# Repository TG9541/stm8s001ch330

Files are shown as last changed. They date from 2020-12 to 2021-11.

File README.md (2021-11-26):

# STM8S001J3M3 with CH330N USB Serial Dongle 



This is a design for an easy to use and easy to make key-chain sized STM8S001J3M3 dongle with CH330N USB-UART, e.g. for [STM8 eForth](https://github.com/TG9541/stm8ef) (which turns it into an interactive development environment). It can also be for interfacing, e.g., 1Wire or I2C sensors, as an IR-code transmitter, or prototyping software for "Low density" STM8S µCs (which all have 8K Flash, 1K RAM and 128-640 bytes EEPROM). If you're an 8bit computing and retro-computing affectionado: the typical performance is like a "6502 @ >20MHz" and it's about as easy to program.



The STM8S001J3M3 UART works in "half-duplex" mode (`PD5/UART_TX`) with the CH330N USB-UART in wired-or configuration (D1). The internal pull-up of `PD5` should be active (the STM8 eForth [STM8S001J3](https://github.com/TG9541/stm8ef/tree/master/STM8S001J3) base image takes care of that). This configuration allows IAP (in application programming) in Forth and ICP (in circuit programming) through `PD1/SWIM` through pin8 of the µC.

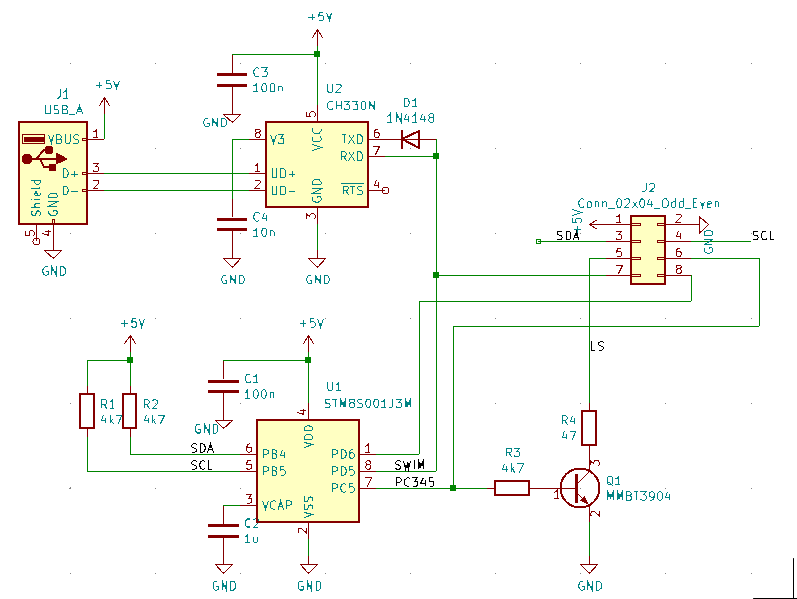
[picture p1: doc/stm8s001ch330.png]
schematics


All components, including the PCB and the SMD USB-A connector are easy to obtain (e.g. [here](https://www.aliexpress.com/item/32900067411.html) for the USB connector - refer to the BOM is in the docs folder).



### Signals on Header J2

J2 provides the following signals:

Pin|Label|Pin STM8S001|GPIO|Features
-|-|-|-|-
1|5V|4|VDD|5V from USB or external supply
2|GND|2|VSS|GND
3|SDA|5|PB5 | I2C_SDA w/ 4k7 pull-up
-||5|PA3 | TIM2_CH3, [SPI_NSS], [UART1_TX]
4|SCL|6|PB4 | I2C_SCL w/ 4k7 pull-up, [ADC_ETR]
5|LSS| |PC3| NPN "Low Side" switch w/ 47R, e.g. IR LED @ 100mA
6|PC3|7|PC3 | TIM1_CH3, [TLI], [TIM1_CH1N] same as LS NPN base
-||7|PC4 | TIM1_CH4, CLK_CCO, AIN2, [TIM1_CH3]
-||7|PC5 | SPI_SCK, [TIM2_CH1]
7|SWIM|8|PD1 | SWIM
-||8|PC6 | SPI_MOSI, [TIM1_CH1]
-||8|PD3 | TIM2_CH2, TIM2_CH2, ADC_ETR
-||8|PD5 | UART1_TX, AIN5
8|PD6|1|PD6| UART1_RX, AIN6
-||1|PA1|[OSC_IN]
 
Note: the circuit relies on the USB port short-circuit protection!

### Example use-cases

* Pins 1, 2, 3 and 4 can be used for testing I2C modules w/ 5V supply (e.g. [STM8 eForth I2C Master](https://gist.github.com/TG9541/5c3405320794d91ef8129734a4bfc880#gistcomment-3565181))
* Pins 1 and 5 can be used for a 100mA IR LED (e.g. [IR Remote Control](https://gist.github.com/TG9541/40b811c3a611eb02ba9e3693f99222ac))
* Pins 1, 2 and 8 can be used for connecting an IR receiver
* Pins 1, 2 and 3 can control a [WS2812 LED strip](https://gist.github.com/TG9541/1761fa86b425a0c909b7bd1cc8017c2b)
* Pin 3 and can be used for RS485 after remapping the UART to PA3 (e.g. using the Forth SWIMCOM binary)
* [Learn programming Forth ...](https://github.com/TG9541/stm8ef/wiki/STM8-eForth-Programming)

### Populating the PCB

Populating the PCB by hand is easy. I recommend starting with D1, then U1, U2, C1 and C2. On the front side populate Q1 and the passive components first, then J1 and finally J2. 

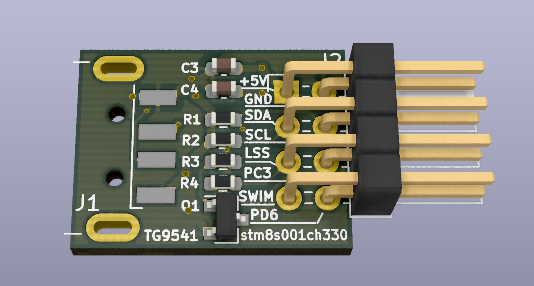
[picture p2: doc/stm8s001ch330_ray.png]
dongle


The following components are optional (e.g. if J2 isn't needed): R1, R2, R3, R4, Q1 and J2.

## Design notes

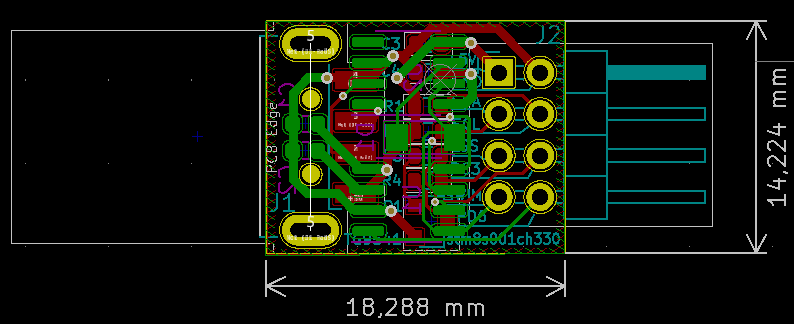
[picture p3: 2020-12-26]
doc/stm8s001ch330_copper.png

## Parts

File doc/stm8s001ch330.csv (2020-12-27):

Reference | Value | Footprint | Datasheet
C2 | 1u | Capacitor_SMD:C_0603_1608Metric | ~
J1 | USB_A | Connector_USB:USB_A_CNCTech_1001-011-01101_Horizontal | ~
C4 | 10n | Capacitor_SMD:C_0603_1608Metric | ~
C3 | 100n | Capacitor_SMD:C_0603_1608Metric | ~
C1 | 100n | Capacitor_SMD:C_0603_1608Metric | ~
R1 | 4k7 | Resistor_SMD:R_0603_1608Metric | ~
R2 | 4k7 | Resistor_SMD:R_0603_1608Metric | ~
D1 | 1N4148 | Diode_SMD:D_MiniMELF | ~
R3 | 4k7 | Resistor_SMD:R_0603_1608Metric | ~
R4 | 47 | Resistor_SMD:R_0603_1608Metric | ~
J2 | Conn_02x04_Odd_Even | Connector_PinHeader_2.54mm:PinHeader_2x04_P2.54mm_Horizontal | ~
Q1 | MMBT3904 | Package_TO_SOT_SMD:SOT-23 | https://www.onsemi.com/pub/Collateral/2N3903-D.PDF
U2 | CH330N | Package_SO:SOIC-8_3.9x4.9mm_P1.27mm | http://www.wch.cn/downloads/file/240.html
U1 | STM8S001J3M | Package_SO:SOIC-8_3.9x4.9mm_P1.27mm | https://www.st.com/resource/en/datasheet/stm8s001j3.pdf

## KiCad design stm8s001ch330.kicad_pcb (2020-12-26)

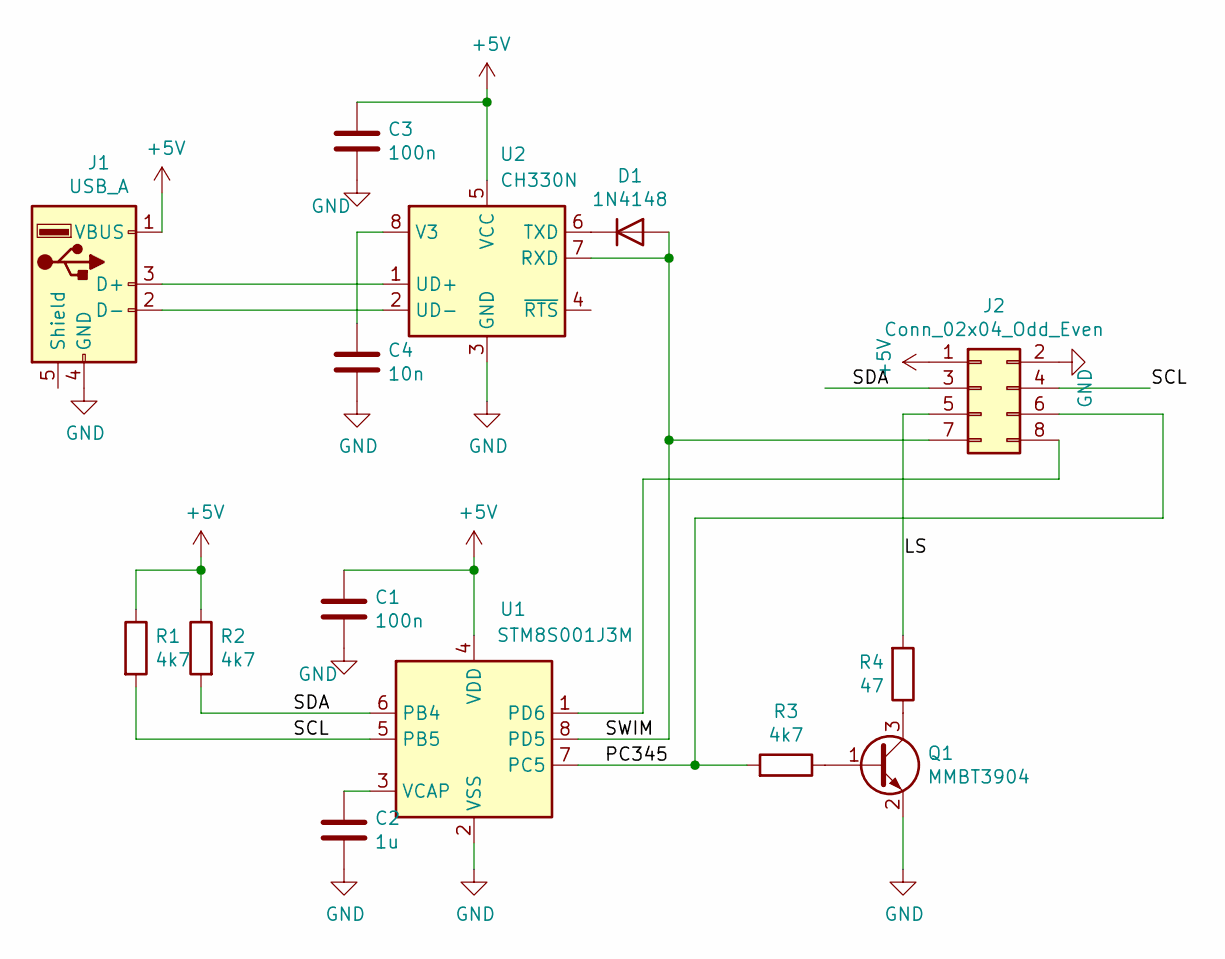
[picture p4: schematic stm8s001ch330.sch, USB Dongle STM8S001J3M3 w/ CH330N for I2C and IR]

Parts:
C1, C3: 100n; C_0603_1608Metric
C2: 1u; C_0603_1608Metric
C4: 10n; C_0603_1608Metric
D1: 1N4148; D_MiniMELF
J1: USB_A; USB_A_CNCTech_1001-011-01101_Horizontal
J2: Conn_02x04_Odd_Even; PinHeader_2x04_P2.54mm_Horizontal
Q1: MMBT3904; SOT-23
R1, R2, R3: 4k7; R_0603_1608Metric
R4: 47; R_0603_1608Metric
U1: STM8S001J3M; SOIC-8_3.9x4.9mm_P1.27mm
U2: CH330N; SOIC-8_3.9x4.9mm_P1.27mm

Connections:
+5V: C1.1, C3.1, J1.1 (VBUS), J2.1, R1.1, R2.1, U1.4 (VDD), U2.5 (VCC)
/LS: J2.5, R4.2
/PC345: J2.6, R3.2, U1.7 (PC5)
/SCL: J2.4, R1.2, U1.5 (PB5)
/SDA: J2.3, R2.2, U1.6 (PB4)
/SWIM: D1.2 (A), J2.7, U1.8 (PD5), U2.7 (RXD)
GND: C1.2, C2.2, C3.2, C4.2, J1.4 (GND), J2.2, Q1.2 (E), U1.2 (VSS), U2.3 (GND)
unnamed: C2.1, U1.3 (VCAP)
unnamed: C4.1, U2.8 (V3)
unnamed: D1.1 (K), U2.6 (TXD)
unnamed: J1.2 (D-), U2.2 (UD-)
unnamed: J1.3 (D+), U2.1 (UD+)
unnamed: J2.8, U1.1 (PD6)
unnamed: Q1.1 (B), R3.1
unnamed: Q1.3 (C), R4.1

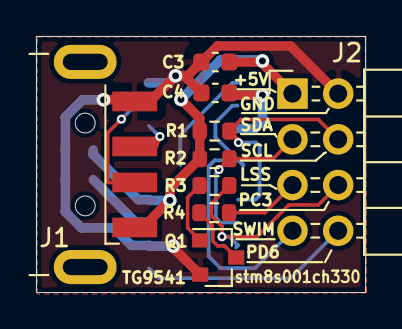
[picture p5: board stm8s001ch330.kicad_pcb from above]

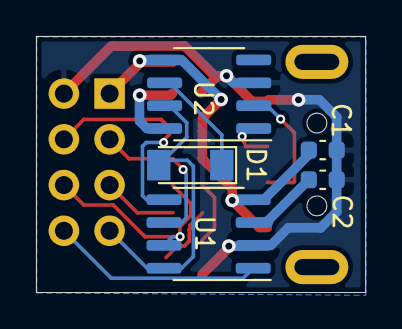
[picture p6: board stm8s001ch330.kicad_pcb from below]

Board: 2 copper layers, 18.3 x 14.2 mm, 14 parts (5 on the bottom side), 15 nets.
